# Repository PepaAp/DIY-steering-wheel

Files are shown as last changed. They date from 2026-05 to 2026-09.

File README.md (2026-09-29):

# DIY Sim Steering Wheel & Pedals 🏎️

Maturitní projekt zaměřený na návrh a stavbu vlastního herního ovladače (volantu a pedálů) pro PC. Projekt kombinuje 3D tisk, vlastní elektroniku a programování mikrokontrolerů.

## 📋 Přehled projektu
Cílem je vytvořit funkční sestavu volantu a dvou pedálů (plyn/brzda), která bude systémem rozpoznána jako standardní herní zařízení (HID).

- **Hlavní jednotka:** Arduino Leonardo (díky čipu ATmega32U4 pro nativní USB podporu).
- **Rozšíření/Bezdrát:** ESP32 (pro budoucí funkce nebo specifické výpočty).
- **Konfigurace:** Volant, 2x Pedál (zatím).

## 🛠️ Seznam komponent
### Elektronika
* **Mikrokontroler:** Arduino Leonardo
* **Sekundární čip:** ESP32
* **Senzory:** Potenciometry, rotační enkodér
* **Tlačítka:** možná později

### Mechanické části
* **Ložiska:** (např. 608RS pro hřídel volantu)
* **Pružiny:** Pro odpor pedálů

## ⚡ Schéma zapojení
Schéma zapojení

Interaktivní návrh a editace schématu: [CircuitDesigner](https://app.cirkitdesigner.com/project/f1c80817-fc01-414b-a5b8-d68fa57e7eee)

## 🖨️ 3D Tisk & Filament
Všechny mechanické části jsou navrženy pro 3D tisk.
* **Složka se soubory:** `/stl`
* **Materiál:** PLA / PETG (doporučeno PETG pro vyšší pevnost pedálů)
* **Předpokládaná spotřeba:** cca **X.X kg** (bude upřesněno po finálním exportu všech dílů)

## 💻 Software & Kód
Zdrojový kód pro Arduino i ESP32 se nachází ve složce `/src`.
* Využívá knihovnu `Joystick.h` pro Arduino Leonardo.
* Komunikace mezi ESP32 a Leonardem probíhá přes serial.

## 📅 Harmonogram a Progres
*Zde bude doplňován měsíční přehled splněných cílů.*

### [Měsíc, např. Září]
- [x] Rešerše komponent a výběr elektroniky.
- [x] Návrh základního mechanismu volantu.
- [ ] První prototyp pedálu.

---

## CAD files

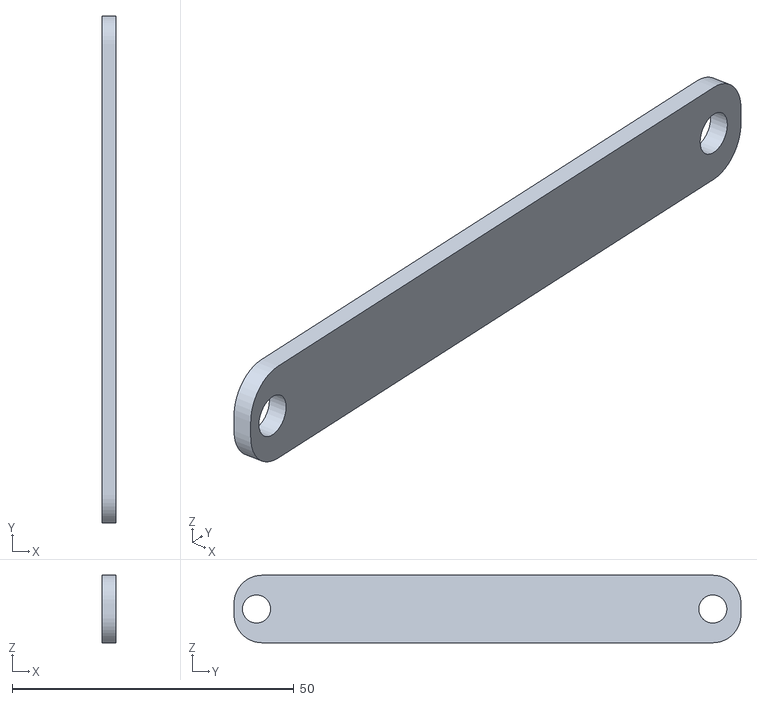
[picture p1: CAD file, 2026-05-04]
stl/pedaly/paka2 v1.stl
2.40 x 90.0 x 12.0

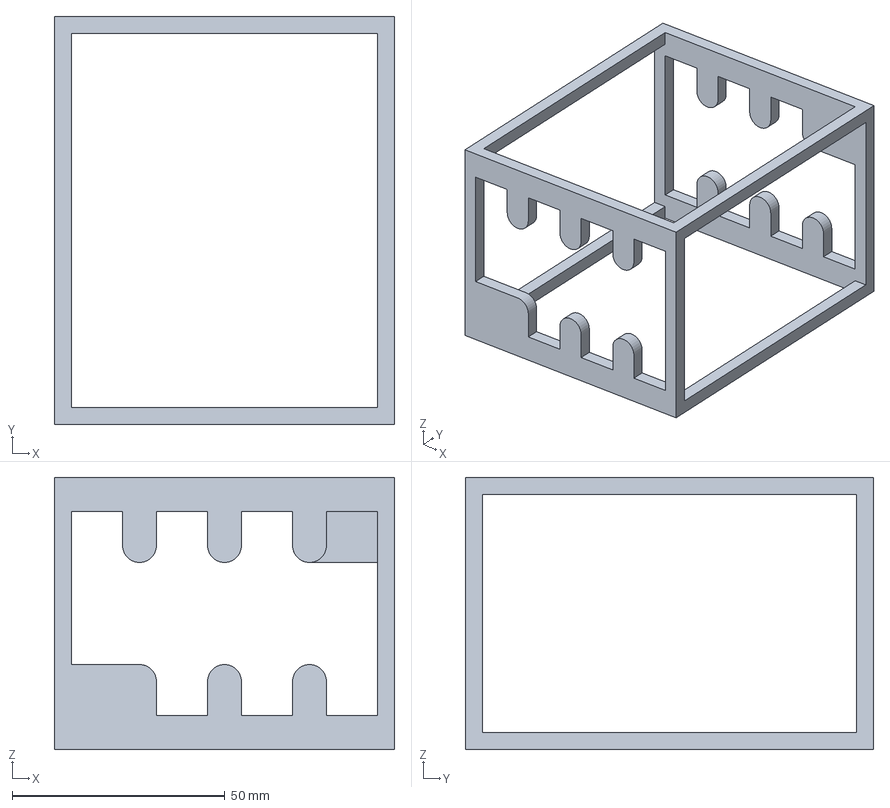
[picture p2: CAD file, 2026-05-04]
stl/radici paka/h shifter.3mf
80.0 x 96.0 x 64.0 mm

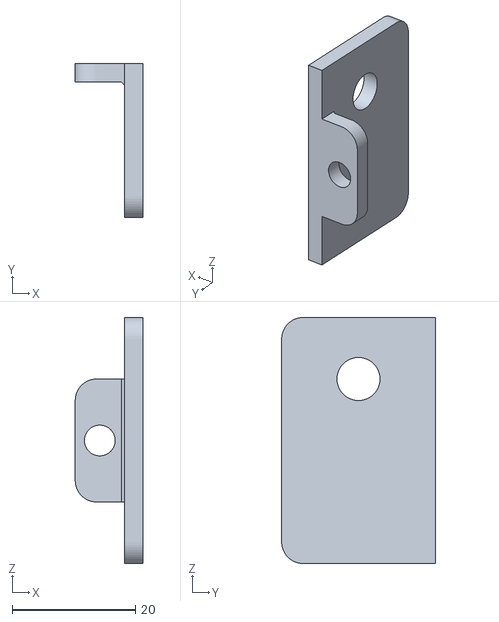
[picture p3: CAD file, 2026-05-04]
stl/volant/drzak na potenciometer v1.stl
11.0 x 25.0 x 40.0

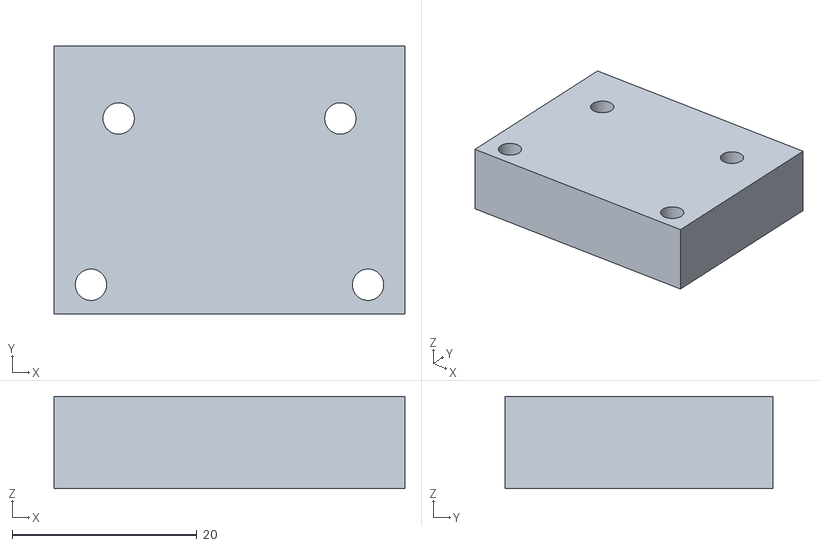
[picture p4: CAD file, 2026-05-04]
stl/volant/enkoder/pod enkoder.stl
38.0 x 29.0 x 10.0

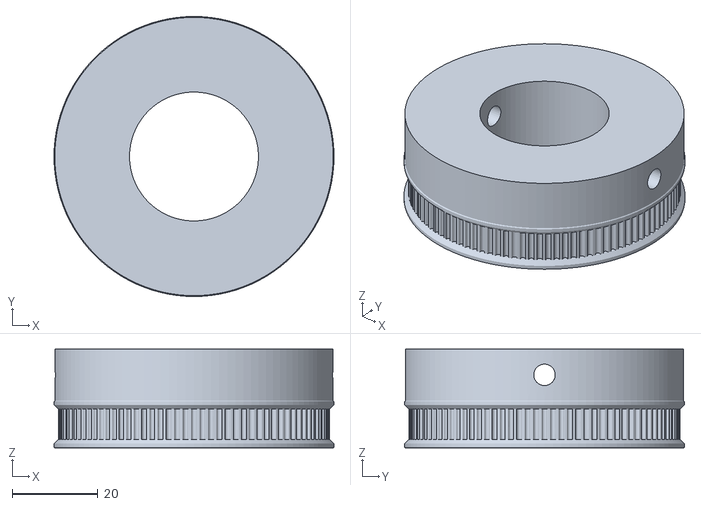
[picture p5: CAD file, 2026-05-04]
stl/volant/kolecka/gearwheel finalni nejvetsi.stl
65.2 x 65.2 x 23.0

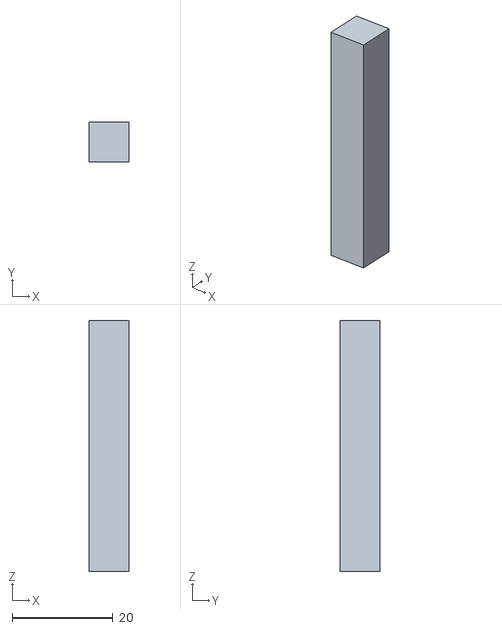
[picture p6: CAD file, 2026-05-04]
stl/volant/ostatni/pod motorek.stl
8.00 x 8.00 x 49.8

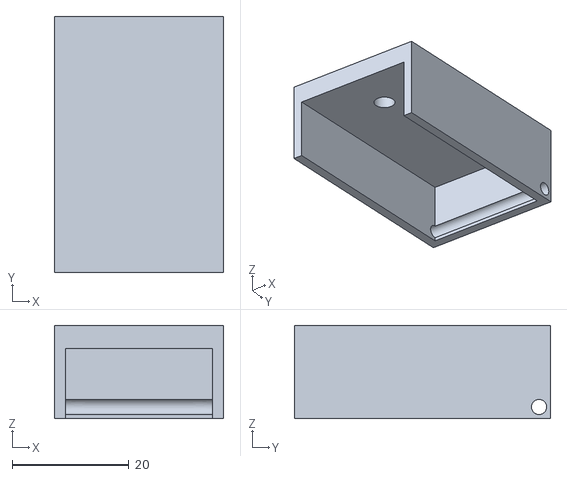
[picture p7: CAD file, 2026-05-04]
stl/volant/packy/prototypy/krytka hlavni.stl
29.0 x 44.0 x 16.0

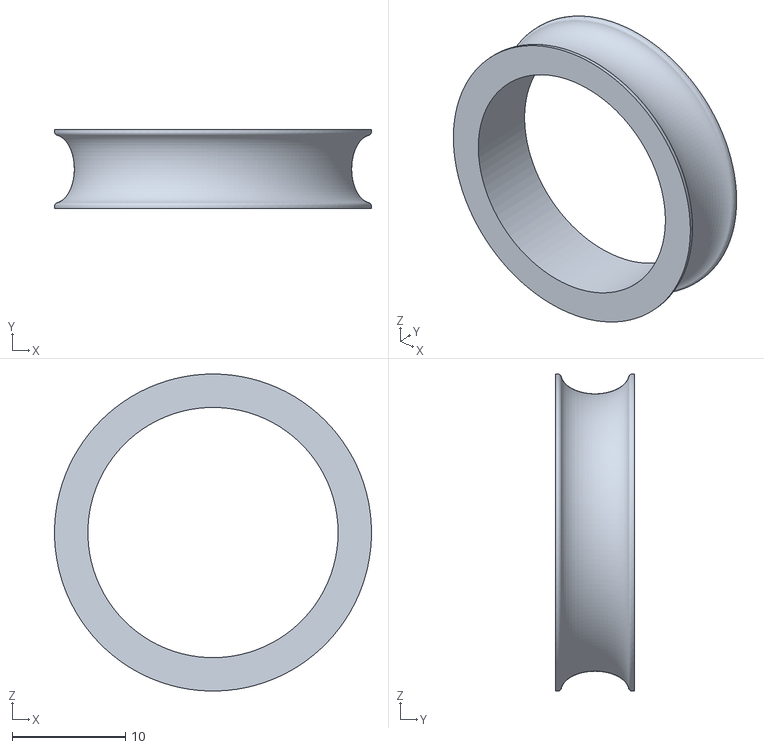
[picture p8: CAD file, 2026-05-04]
stl/pedaly/pully for bearing.stl
28.0 x 7.00 x 28.0

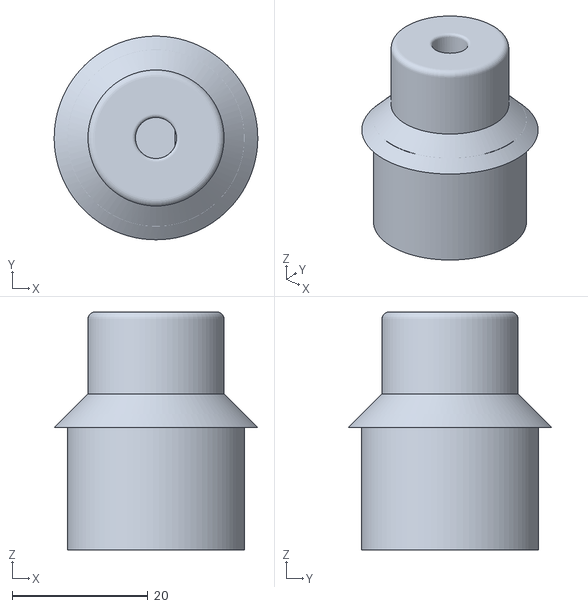
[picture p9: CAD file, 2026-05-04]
stl/volant/enkoder/koncovka na trubku pro enkoder v1.stl
29.9 x 29.9 x 35.0

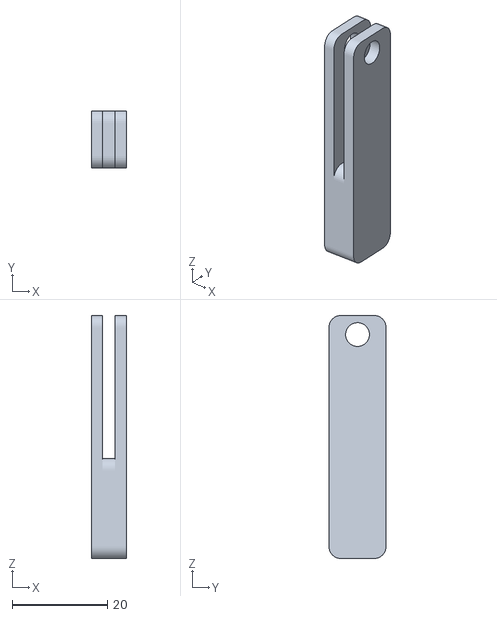
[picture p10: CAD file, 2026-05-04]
stl/pedaly/PAKA1 v2.stl
7.40 x 12.0 x 51.0

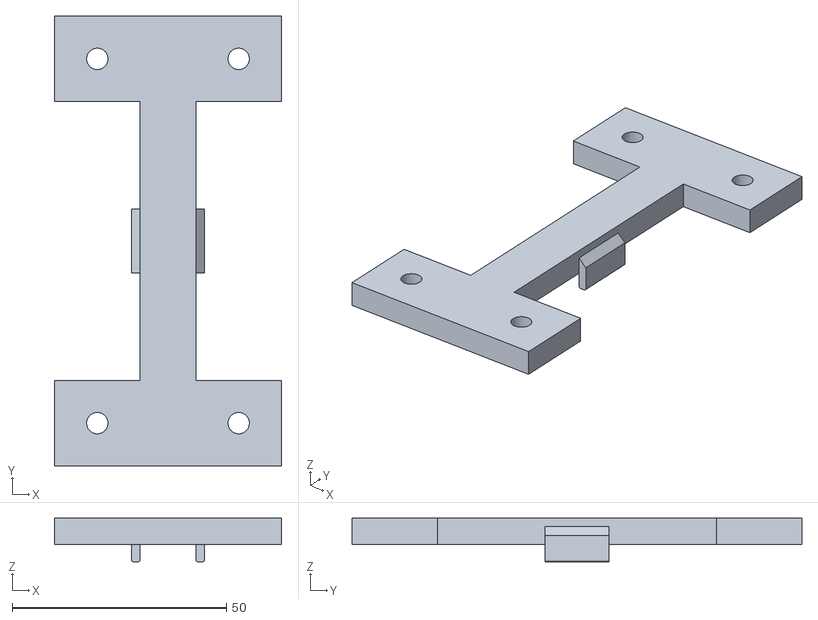
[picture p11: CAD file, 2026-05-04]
stl/volant/loziska/drzak na lozisko v bedne v3.stl
53.0 x 105.0 x 10.2

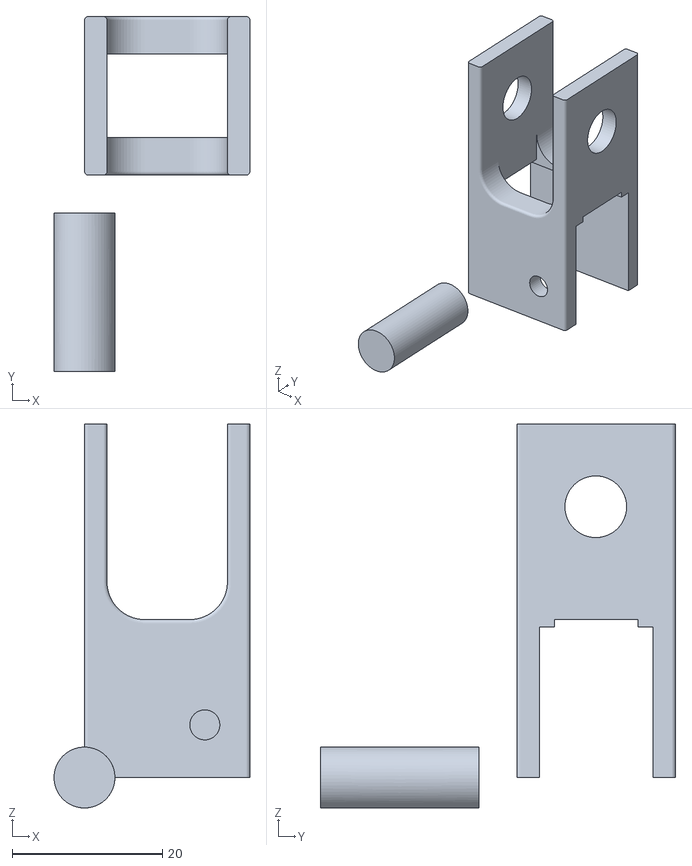
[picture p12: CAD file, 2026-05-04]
stl/pedaly/lozisko pedaly drzak.stl
26.0 x 47.2 x 51.1

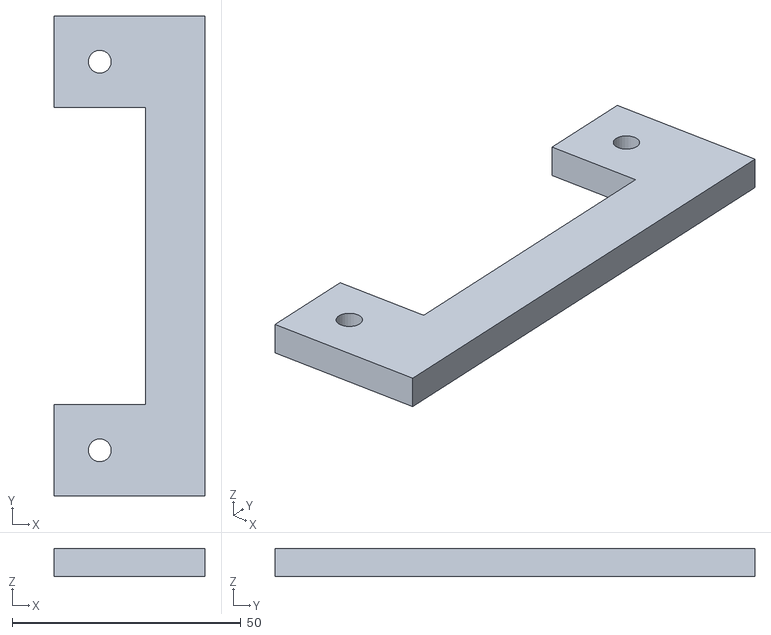
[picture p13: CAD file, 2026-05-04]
stl/volant/loziska/drzak na lozisko v bedne 2.stl
33.0 x 105.0 x 6.20

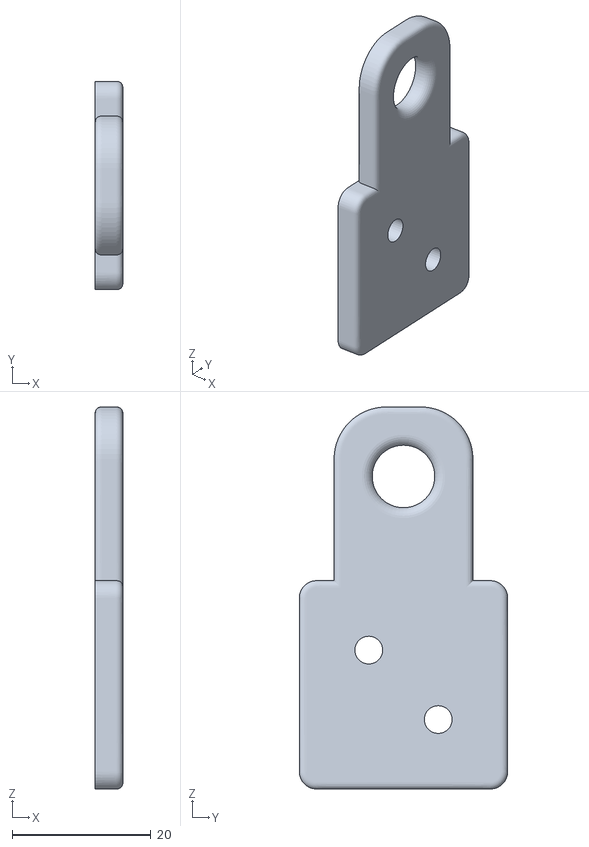
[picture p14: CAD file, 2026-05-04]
stl/pedaly/provazek dryak v0.stl
4.00 x 30.0 x 55.0

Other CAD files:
stl/volant/loziska/drzak na lozisko v bedne dodatek.stl
stl/volant/packy/prototypy/krytka hlavni v8.stl
stl/volant/loziska/gearwheel 30 bigger v1.stl
stl/volant/packy/prototypy/packa mala ohyb.stl
stl/pedaly/PAKA1 v1.stl
stl/volant/loziska/drzak na lozisko v bedne v0.stl
stl/volant/loziska/drzak na lozisko v bedne v1.stl
stl/volant/packy/prototypy/horni dil v1.stl
stl/volant/packy/prototypy/horni dil v2.stl
stl/volant/packy/prototypy/krytka hlavni v2.stl
stl/volant/packy/prototypy/krytka hlavni v7.stl
stl/volant/packy/prototypy/packa mala ohyb v8.3mf
stl/volant/packy/prototypy/packa mala ohyb v8.stl

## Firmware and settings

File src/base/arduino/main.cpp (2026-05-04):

#include <Joystick.h> 

#define button1 9
#define button2 8
#define button3 7
#define clutchPin A1
#define breakPin A2
#define gasPin A3
#define encoderA 2
#define encoderB 3
#define RPWM 6
#define LPWM 5

Joystick_ Joystick(0x1, JOYSTICK_TYPE_JOYSTICK, 3, 0, true, false, true, false, false, false, false, true, false, true, true);

int lastButton1State = true;
int lastButton2State = true;
int lastButton3State = true;
int steerValue = 0;
int steerValueJoystick = 0;
int lastA;

void steering() {
    int A = digitalRead(encoderA);
    int B = digitalRead(encoderB);

    if (A != lastA) {
        if (B != A) {
            steerValue++;
        } else {
            steerValue--;
        }
    }
    lastA = A;
}

void setup() {
    lastA = digitalRead(encoderA);
    Serial.begin(9600);

    pinMode(button1, INPUT_PULLUP);
    pinMode(button2, INPUT_PULLUP);
    pinMode(button3, INPUT_PULLUP);
    pinMode(clutchPin, INPUT);
    pinMode(breakPin, INPUT);
    pinMode(gasPin, INPUT);
    pinMode(encoderA, INPUT);
    pinMode(encoderB, INPUT);
    pinMode(RPWM, OUTPUT);
    pinMode(LPWM, OUTPUT);    
    TCCR4B = (TCCR4B & 0b11111000) | 0x01;
    TCCR3B = (TCCR3B & 0b11111000) | 0x01;
    attachInterrupt(digitalPinToInterrupt(encoderA), steering, CHANGE); 
    analogWrite(RPWM, 0);
    analogWrite(LPWM, 0);
    Joystick.begin();
    delay(5);
}

void loop() {
    int button1State = digitalRead(button1);
    int button2State = digitalRead(button2);
    int button3State = digitalRead(button3);
    int clutchValue = map(analogRead(clutchPin), 280, 400, 0, 1023);
    int breakValue = map(analogRead(breakPin), 440, 550, 0, 1023);
    int gasValue = map(analogRead(gasPin), 320, 450, 0, 1023);
    int motorRight = map(steerValueJoystick, 513, 1024, 60, 255);
    int motorLeft = map(steerValueJoystick, 0, 511, 255, 60);
    /* digitalWrite(LPWM, LOW);
    analogWrite(RPWM, 255); */

    Joystick.setZAxis(clutchValue);
    Joystick.setThrottle(gasValue);
    Joystick.setBrake(breakValue);

    steerValueJoystick = constrain(map(steerValue, -2560, 2560, 0, 1024), 0, 1024);

    
    Serial.print("raw value ");
    Serial.print(steerValue);
    Serial.print(" mapped value ");
    Serial.println(steerValueJoystick);
    
    /* Serial.println(gasValue);
    Serial.println(breakValue);
    Serial.println(clutchValue); */
    
    if (steerValueJoystick < 512) {
        analogWrite(LPWM, motorLeft);
        digitalWrite(RPWM, LOW);
    } else if (steerValueJoystick == 512) {
        analogWrite(RPWM, 0);
        analogWrite(LPWM, 0);
    } else {
        analogWrite(RPWM, motorRight);
        digitalWrite(LPWM, LOW);
    }

    Joystick.setXAxis(steerValueJoystick);
    Joystick.sendState();

    if (button1State != lastButton1State) {
        Joystick.setButton(0, button1State == LOW);
        lastButton1State = button1State;
    }
    if (button2State != lastButton2State) {
        Joystick.setButton(1, button2State == LOW);
        lastButton2State = button2State;
    }
    if (button3State != lastButton3State) {
        Joystick.setButton(2, button3State == LOW);
        lastButton3State = button3State;
    }

    

    delay(5);
}

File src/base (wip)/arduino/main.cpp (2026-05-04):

#include <Joystick.h>

#define button1 9
#define button2 8
#define button3 7
#define encoderA 2
#define encoderB 3
#define RPWM 6
#define LPWM 5

#define defClutch 650
#define defBreak  970
#define defGas    1300
#define maxClutch 1320
#define maxBreak  1620
#define maxGas    2120

Joystick_ Joystick(0x1, JOYSTICK_TYPE_JOYSTICK, 3, 0, true, false, true, false, false, false, false, true, false, true, true);

volatile int steerValue = 0;
volatile int lastA;

int lastButton1State = HIGH;
int lastButton2State = HIGH;
int lastButton3State = HIGH;

int steerValueJoystick = 0;

uint16_t gasRaw = defGas, brakeRaw = defBreak, clutchRaw = defClutch;

char serialBuffer[64];
uint8_t serialIndex = 0;

void steering() {
    int A = digitalRead(encoderA);
    int B = digitalRead(encoderB);
    if (A != lastA) steerValue += (B != A) ? 1 : -1;
    lastA = A;
}

void parseData(char* dataLine) {
    int g=0,b=0,c=0;
    if (sscanf(dataLine, "%d,%d,%d", &g, &b, &c) != 3) return;
    gasRaw = g;
    brakeRaw = b;
    clutchRaw = c;
}

void setup() {
    lastA = digitalRead(encoderA);
    pinMode(button1, INPUT_PULLUP);
    pinMode(button2, INPUT_PULLUP);
    pinMode(button3, INPUT_PULLUP);
    pinMode(encoderA, INPUT);
    pinMode(encoderB, INPUT);
    pinMode(RPWM, OUTPUT);
    pinMode(LPWM, OUTPUT);

    TCCR4B = (TCCR4B & 0b11111000) | 0x01;
    TCCR3B = (TCCR3B & 0b11111000) | 0x01;

    attachInterrupt(digitalPinToInterrupt(encoderA), steering, CHANGE);

    analogWrite(RPWM, 0);
    analogWrite(LPWM, 0);

    Serial.begin(9600);
    Serial1.begin(9600);
    Joystick.begin();
}

void loop() {
    int b1 = digitalRead(button1);
    if (b1 != lastButton1State) { Joystick.setButton(0, b1==LOW); lastButton1State=b1; }
    int b2 = digitalRead(button2);
    if (b2 != lastButton2State) { Joystick.setButton(1, b2==LOW); lastButton2State=b2; }
    int b3 = digitalRead(button3);
    if (b3 != lastButton3State) { Joystick.setButton(2, b3==LOW); lastButton3State=b3; }

    while (Serial1.available()) {
        char c = Serial1.read();
        if (c=='\n') {
            serialBuffer[serialIndex] = 0;
            parseData(serialBuffer);
            serialIndex = 0;
        } else if (serialIndex<sizeof(serialBuffer)-1) serialBuffer[serialIndex++] = c;
    }

    int gasMapped = constrain(map(gasRaw, defGas, maxGas, 0, 1023), 0, 1023);
    int brakeMapped = constrain(map(brakeRaw, defBreak, maxBreak, 0, 1023), 0, 1023);
    int clutchMapped = constrain(map(clutchRaw, defClutch, maxClutch, 0, 1023), 0, 1023);

    Joystick.setThrottle(gasMapped);
    Joystick.setBrake(brakeMapped);
    Joystick.setZAxis(clutchMapped);

    steerValueJoystick = constrain(map(steerValue, -2560, 2560, 0, 1024), 0, 1024);
    int motorRight = map(steerValueJoystick, 513, 1024, 60, 255);
    int motorLeft  = map(steerValueJoystick, 0, 511, 255, 60); // normalne je misto 115 255 ale rozbil se mi motorek


    Serial.println(motorRight);
    if (steerValueJoystick < 512) { analogWrite(LPWM, motorLeft > 115 ? 115: motorLeft); digitalWrite(RPWM, LOW); }
    else if (steerValueJoystick > 512) { analogWrite(RPWM, motorRight > 115 ? 115: motorRight); digitalWrite(LPWM, LOW); }
    else { analogWrite(RPWM, 0); analogWrite(LPWM, 0); }

    Joystick.setXAxis(steerValueJoystick);
    Joystick.sendState();
}
